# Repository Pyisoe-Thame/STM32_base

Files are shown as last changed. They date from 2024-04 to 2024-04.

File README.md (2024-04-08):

# Relay with AC PS and STM32

This is my PCB Design practice project.
Flexible programming expandable with sensors through I2C.

## Screenshots

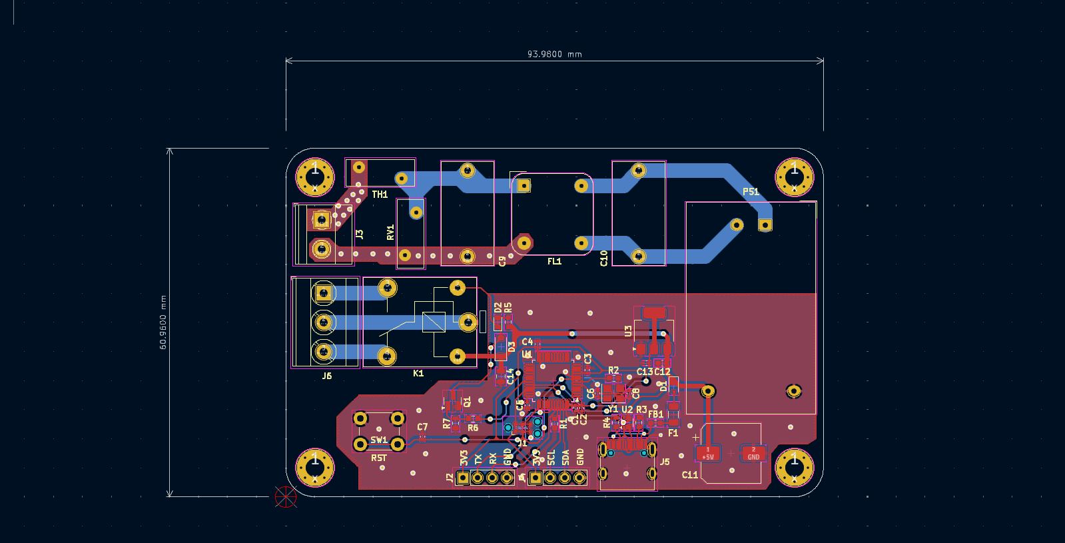
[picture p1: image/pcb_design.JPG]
PCB Design

<p align="center">PCB Design</p>

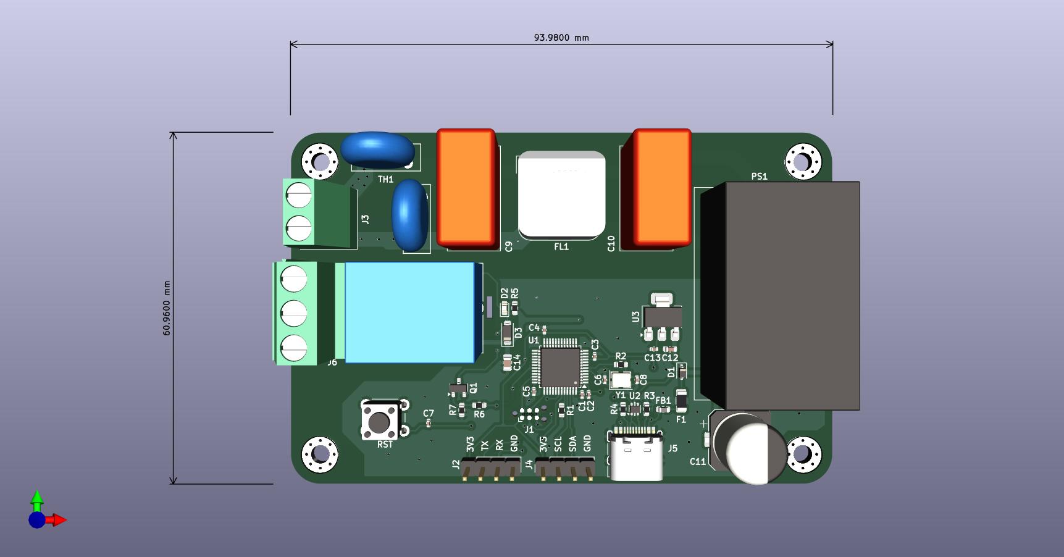
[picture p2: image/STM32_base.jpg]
3D view

<p align="center">3D View</p>

## Features

- AC Power Supply to 5V, 3V3
- STM32F103C8T6
- SWD J Tag Connector
- USB Type C 2.0
- USART, I2C
- 5V Relay

## License

[MIT](https://choosealicense.com/licenses/mit/)

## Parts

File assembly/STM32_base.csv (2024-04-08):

Reference | Value | Datasheet | Footprint | Qty | DNP
C1,C2,C3,C4,C5,C7,C13 | 100nF | ~ | Capacitor_SMD:C_0402_1005Metric | 7
C6,C8 | 22pF | ~ | Capacitor_SMD:C_0402_1005Metric | 2
C9,C10 | 1uF | ~ | Capacitor_THT:C_Rect_L18.0mm_W9.0mm_P15.00mm_FKS3_FKP3 | 2
C11 | 220uF | ~ | Capacitor_SMD:CP_Elec_10x10 | 1
C12 | 1uF | ~ | Capacitor_SMD:C_0603_1608Metric | 1
C14 | 10uF | ~ | Capacitor_SMD:C_0805_2012Metric | 1
D1 | 1N5819WS | https://datasheet.lcsc.com/lcsc/2204281430_Guangdong-Hottech-1N5819WS_C191023.pdf | Diode_SMD:D_SOD-323 | 1
D2 | LED_Small | ~ | LED_SMD:LED_0603_1608Metric | 1
D3 | 1N4148W | https://www.vishay.com/docs/85748/1n4148w.pdf | Diode_SMD:D_SOD-123 | 1
F1 | 1A | ~ | Fuse:Fuse_1206_3216Metric | 1
FB1 | FB | ~ | Inductor_SMD:L_0603_1608Metric | 1
FL1 | Choke_Schaffner_RN102-2-02-1M1 | https://www.schaffner.com/products/download/product/datasheet/rn-series-common-mode-chokes-new/ | Inductor_THT:Choke_Schaffner_RN102-04-14.0x14.0mm | 1
J2,J4 | Conn_01x04_Pin | ~ | Connector_PinHeader_2.54mm:PinHeader_1x04_P2.54mm_Vertical | 2
J3 | ST | ~ | TerminalBlock_Phoenix:TerminalBlock_Phoenix_MKDS-1,5-2-5.08_1x02_P5.08mm_Horizontal | 1
J5 | USB_C_Receptacle_USB2.0_14P | https://www.usb.org/sites/default/files/documents/usb_type-c.zip | Connector_USB:USB_C_Receptacle_HRO_TYPE-C-31-M-12 | 1
J6 | ST | ~ | TerminalBlock_Phoenix:TerminalBlock_Phoenix_MKDS-3-3-5.08_1x03_P5.08mm_Horizontal | 1
K1 | SANYOU_SRD_Form_C | http://www.sanyourelay.ca/public/products/pdf/SRD.pdf | Relay_THT:Relay_SPDT_SANYOU_SRD_Series_Form_C | 1
PS1 | HLK-PM01 | https://h.hlktech.com/download/ACDC%E7%94%B5%E6%BA%90%E6%A8%A1%E5%9D%973W%E7%B3%BB%E5%88%97/1/%E6%B5%B7%E5%87%8C%E7%A7%913W%E7%B3%BB%E5%88%97%E7%94%B5%E6%BA%9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 | Converter_ACDC:Converter_ACDC_Hi-Link_HLK-PMxx | 1
Q1 | BC817 | https://www.onsemi.com/pub/Collateral/BC818-D.pdf | Package_TO_SOT_SMD:SOT-23 | 1
R1,R2 | 47R | ~ | Resistor_SMD:R_0603_1608Metric | 2
R3,R4 | 5k1 | ~ | Resistor_SMD:R_0603_1608Metric | 2
R5 | 1k | ~ | Resistor_SMD:R_0603_1608Metric | 1
R6 | 2k2 | ~ | Resistor_SMD:R_0603_1608Metric | 1
R7 | 47k | ~ | Resistor_SMD:R_0603_1608Metric | 1
RV1 | 10D471k | ~ | Varistor:RV_Disc_D12mm_W4.7mm_P7.5mm | 1
SW1 | RST_BTN |  | Button_Switch_THT:SW_PUSH_6mm | 1
TH1 | 8ohm | ~ | Varistor:RV_Disc_D12mm_W4.7mm_P7.5mm | 1
U1 | STM32F103C8Tx | https://www.st.com/resource/en/datasheet/stm32f103c8.pdf | Package_QFP:LQFP-48_7x7mm_P0.5mm | 1
U2 | USBLC6-2P6 | https://www.st.com/resource/en/datasheet/usblc6-2.pdf | Package_TO_SOT_SMD:SOT-666 | 1
U3 | AMS1117-3.3 | http://www.advanced-monolithic.com/pdf/ds1117.pdf | Package_TO_SOT_SMD:SOT-223-3_TabPin2 | 1
Y1 | 8MHz | ~ | Crystal:Crystal_SMD_3225-4Pin_3.2x2.5mm | 1

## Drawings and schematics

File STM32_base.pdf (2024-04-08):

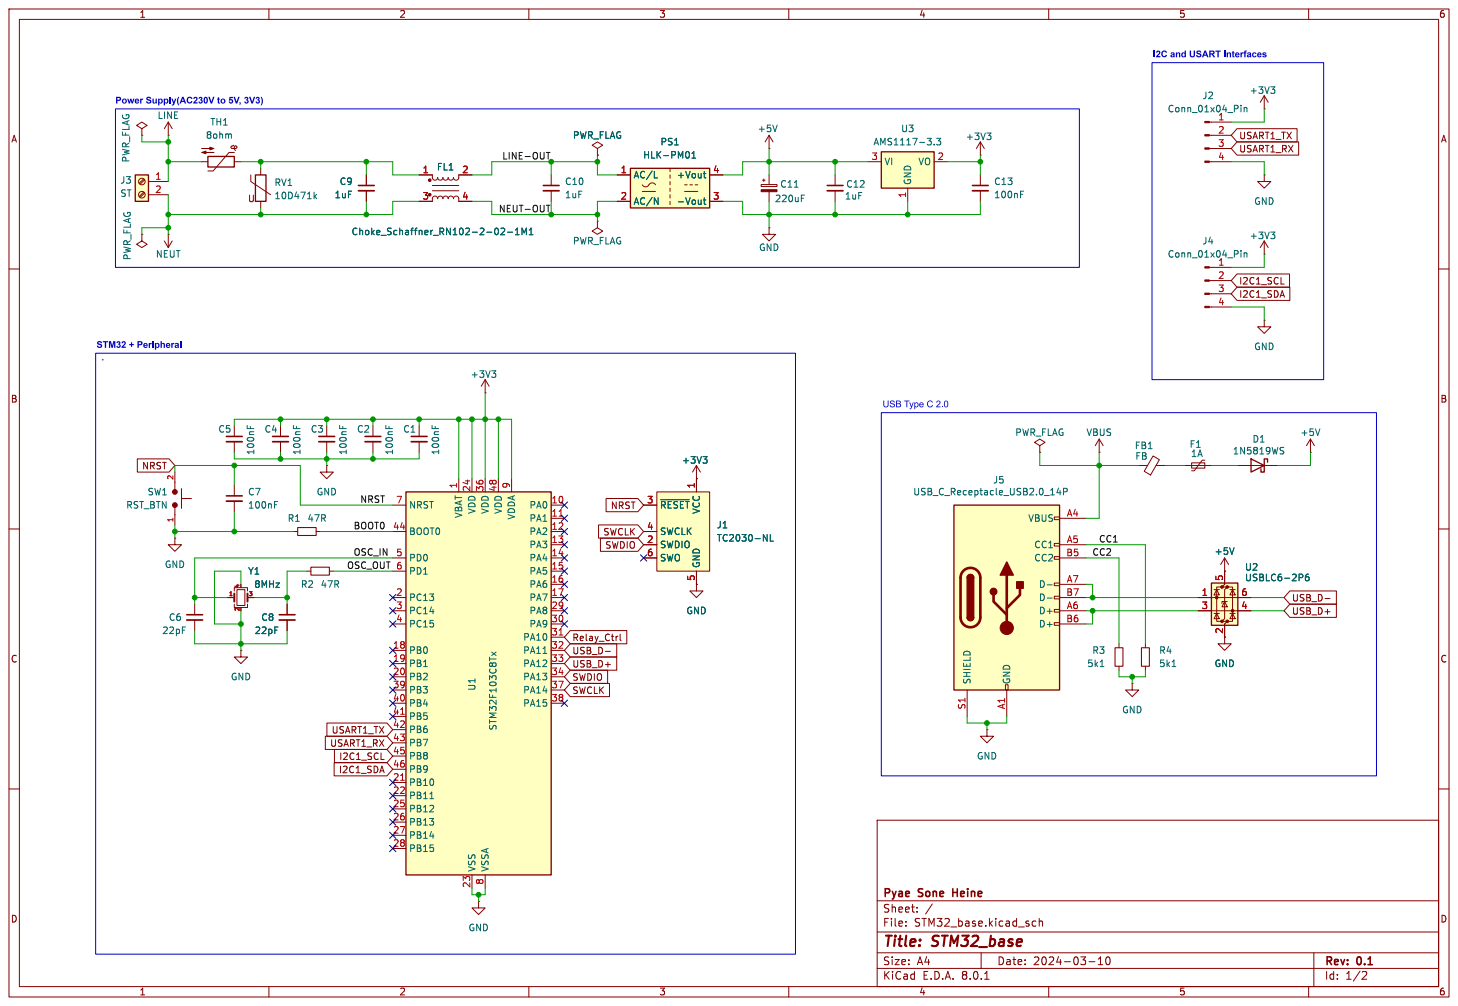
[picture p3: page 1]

1 PA0 10 PA1 11 PA2 12 PA3 13 PA4 14 PA5 15 PA6 16 PA7 17 PB0 18 PB1 19 PC13 2 PB2 20 PB10 21 PB11 22 VSS 23 VDD 24 PB12 25 PB13 26 PB14 27 PB15 28 PA8 29 PC14 3 PA9 30 PA10 31 PA11 32 PA12 33 PA13 34 VDD 36 PA14 37 PA15 38 PB3 39 PC15 4 PB4 40 PB5 41 PB6 42 PB7 43 BOOT0 44 PB8 45 PB9 46 VDD 48 PD0 5 PD1 6 NRST 7 VSSA
GND VBAT

1 SWDIO 2 ~{RESET} 3 SWCLK 4 GND

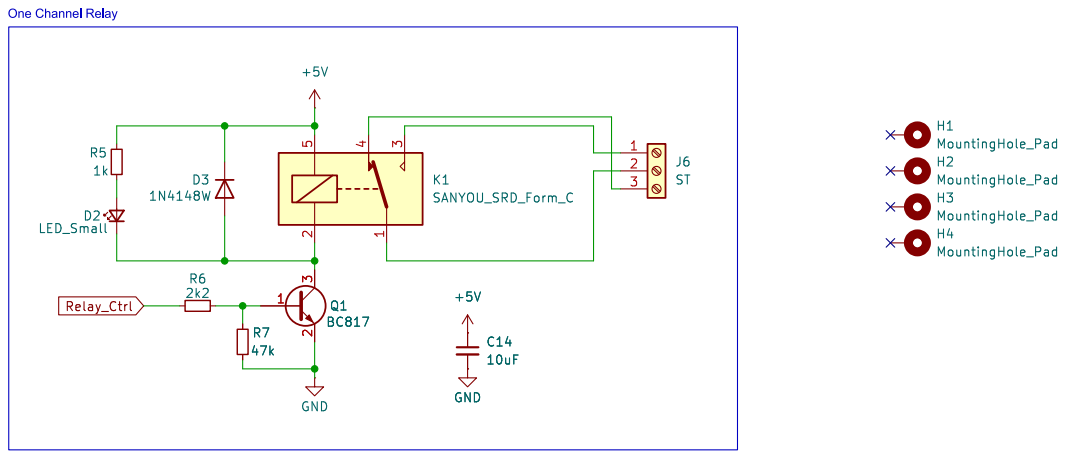
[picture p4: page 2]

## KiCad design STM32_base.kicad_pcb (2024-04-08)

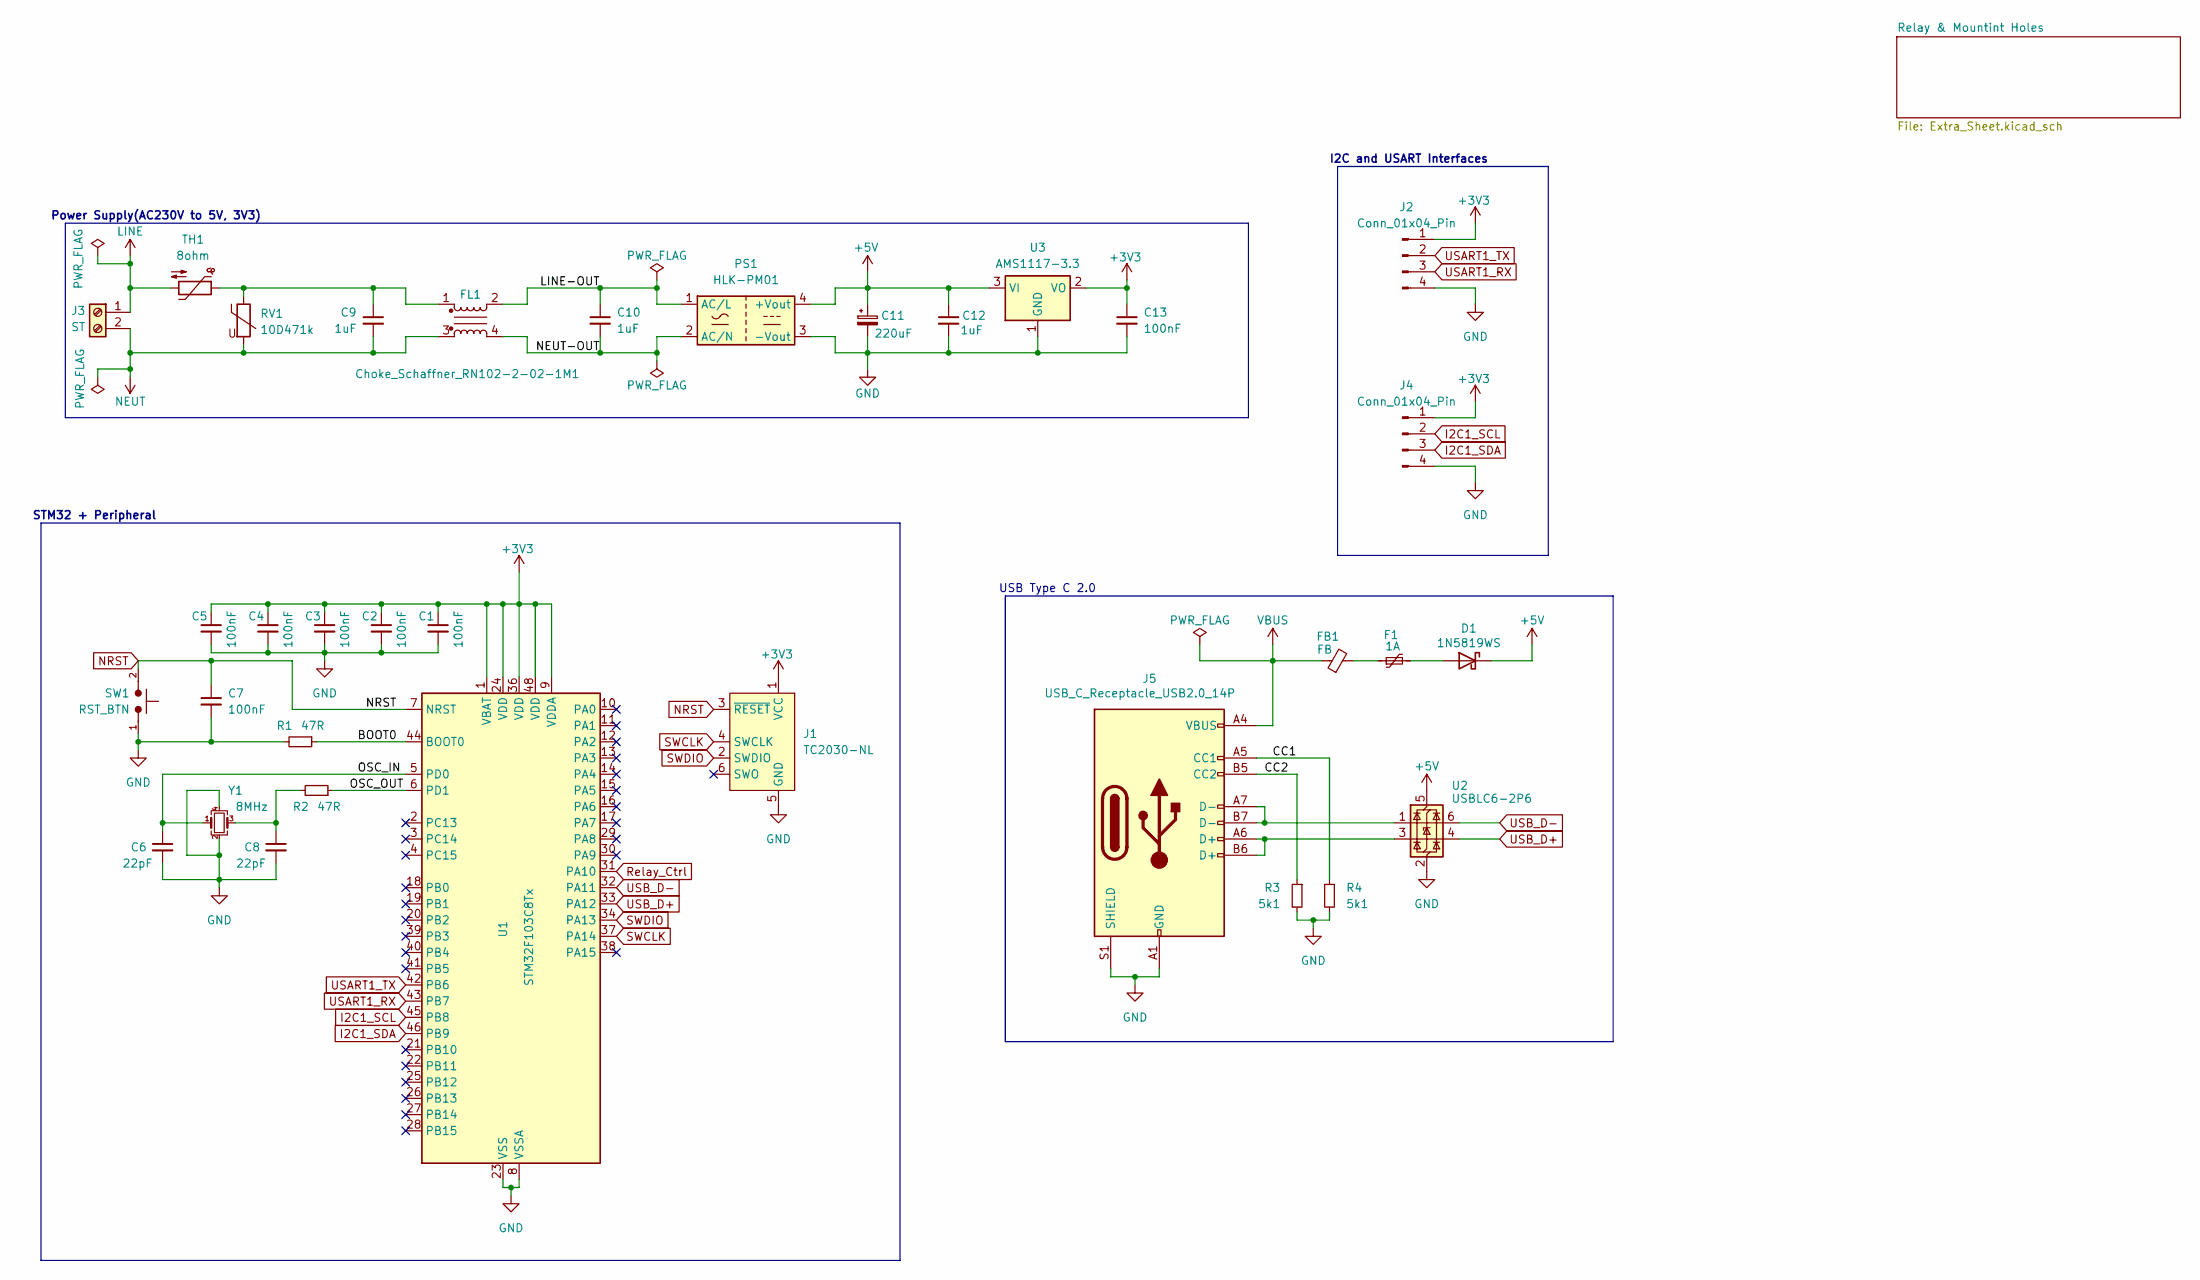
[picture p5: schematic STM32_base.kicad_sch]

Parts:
C1, C2, C3, C4, C5, C7, C13: 100nF; C_0402_1005Metric
C6, C8: 22pF; C_0402_1005Metric
C9, C10: 1uF; C_Rect_L18.0mm_W9.0mm_P15.00mm_FKS3_FKP3
C11: 220uF; CP_Elec_10x10
C12: 1uF; C_0603_1608Metric
D1: 1N5819WS; D_SOD-323
F1: 1A; Fuse_1206_3216Metric
FB1: FB; L_0603_1608Metric
FL1: Choke_Schaffner_RN102-2-02-1M1; Choke_Schaffner_RN102-04-14.0x14.0mm
J1: TC2030-NL; Tag-Connect_TC2030-IDC-NL_2x03_P1.27mm_Vertical
J2, J4: Conn_01x04_Pin; PinHeader_1x04_P2.54mm_Vertical
J3: ST; TerminalBlock_Phoenix_MKDS-1,5-2-5.08_1x02_P5.08mm_Horizont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
J5: USB_C_Receptacle_USB2.0_14P; USB_C_Receptacle_HRO_TYPE-C-31-M-12
PS1: HLK-PM01; Converter_ACDC_Hi-Link_HLK-PMxx
R1, R2: 47R; R_0603_1608Metric
R3, R4: 5k1; R_0603_1608Metric
RV1: 10D471k; RV_Disc_D12mm_W4.7mm_P7.5mm
SW1: RST_BTN; SW_PUSH_6mm
TH1: 8ohm; RV_Disc_D12mm_W4.7mm_P7.5mm
U1: STM32F103C8Tx; LQFP-48_7x7mm_P0.5mm
U2: USBLC6-2P6; SOT-666
U3: AMS1117-3.3; SOT-223-3_TabPin2
Y1: 8MHz; Crystal_SMD_3225-4Pin_3.2x2.5mm

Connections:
+3V3: C1.1, C2.1, C3.1, C4.1, C5.1, C13.1, J1.1 (VCC), J2.1, J4.1, U1.1 (VBAT), U1.9 (VDDA), U1.24 (VDD), U1.36 (VDD), U1.48 (VDD), U3.2 (VO)
+5V: C11.1, C12.1, D1.1 (K), PS1.4 (+Vout), U2.5 (VBUS), U3.3 (VI); also elsewhere on the board
/BOOT0: R1.1, U1.44 (BOOT0)
/CC1: J5.A5 (CC1), R4.1
/CC2: J5.B5 (CC2), R3.1
/LINE-OUT: C10.1, FL1.2, PS1.1 (AC/L)
/NEUT-OUT: C10.2, FL1.4, PS1.2 (AC/N)
/OSC_IN: C6.1, U1.5 (PD0), Y1.1
/OSC_OUT: R2.1, U1.6 (PD1)
GND: C1.2, C2.2, C3.2, C4.2, C5.2, C6.2, C7.2, C8.2, C11.2, C12.2, C13.2, J1.5 (GND), J2.4, J4.4, J5.A1 (GND), J5.A12 (GND), J5.B1 (GND), J5.B12 (GND), J5.S1 (SHIELD), PS1.3 (-Vout), R1.2, R3.2, R4.2, SW1.1, U1.8 (VSSA), U1.23 (VSS), U1.35 (VSS), U1.47 (VSS), U2.2 (GND), U3.1 (GND), Y1.2, Y1.4; also elsewhere on the board
I2C1_SCL: J4.2, U1.45 (PB8)
I2C1_SDA: J4.3, U1.46 (PB9)
LINE: J3.1, TH1.2
NEUT: C9.2, FL1.3, J3.2, RV1.2
NRST: C7.1, J1.3 (~RESET), SW1.2, U1.7 (NRST)
unnamed: C8.1, R2.2, Y1.3
unnamed: C9.1, FL1.1, RV1.1, TH1.1
unnamed: D1.2 (A), F1.2
unnamed: F1.1, FB1.2
unnamed: J5.A6 (D+), J5.B6 (D+), U2.3 (I/O2)
unnamed: J5.A7 (D-), J5.B7 (D-), U2.1 (I/O1)
Relay_Ctrl: U1.31 (PA10); also elsewhere on the board
SWCLK: J1.4 (SWCLK), U1.37 (PA14)
SWDIO: J1.2 (SWDIO), U1.34 (PA13)
USART1_RX: J2.3, U1.43 (PB7)
USART1_TX: J2.2, U1.42 (PB6)
USB_D+: U1.33 (PA12), U2.4 (I/O2)
USB_D-: U1.32 (PA11), U2.6 (I/O1)
VBUS: FB1.1, J5.A4 (VBUS), J5.A9 (VBUS), J5.B4 (VBUS), J5.B9 (VBUS)

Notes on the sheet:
I2C and USART Interfaces
STM32 + Peripheral
Power Supply(AC230V to 5V, 3V3)
USB Type C 2.0

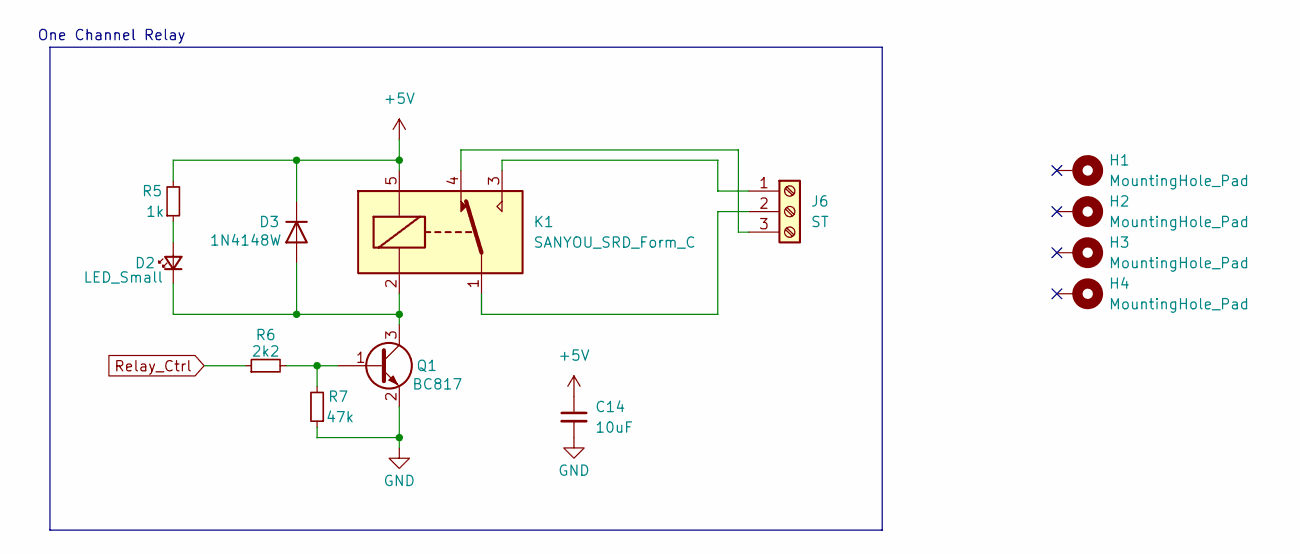
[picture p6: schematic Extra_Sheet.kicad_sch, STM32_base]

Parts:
C14: 10uF; C_0805_2012Metric
D2: LED_Small; LED_0603_1608Metric
D3: 1N4148W; D_SOD-123
H1, H2, H3, H4: MountingHole_Pad; MountingHole_3.2mm_M3_Pad_Via
J6: ST; TerminalBlock_Phoenix_MKDS-3-3-5.08_1x03_P5.08mm_Horizontal
K1: SANYOU_SRD_Form_C; Relay_SPDT_SANYOU_SRD_Series_Form_C
Q1: BC817; SOT-23
R5: 1k; R_0603_1608Metric
R6: 2k2; R_0603_1608Metric
R7: 47k; R_0603_1608Metric

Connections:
+5V: C14.1, D3.1 (K), K1.5, R5.2; also elsewhere on the board
GND: C14.2, Q1.2 (E), R7.1; also elsewhere on the board
unnamed: D2.2 (A), R5.1
unnamed: D2.1 (K), D3.2 (A), K1.2, Q1.3 (C)
unnamed: J6.1, K1.3
unnamed: J6.2, K1.1
unnamed: J6.3, K1.4
unnamed: Q1.1 (B), R6.2, R7.2
Relay_Ctrl: R6.1; also elsewhere on the board

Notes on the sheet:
One Channel Relay

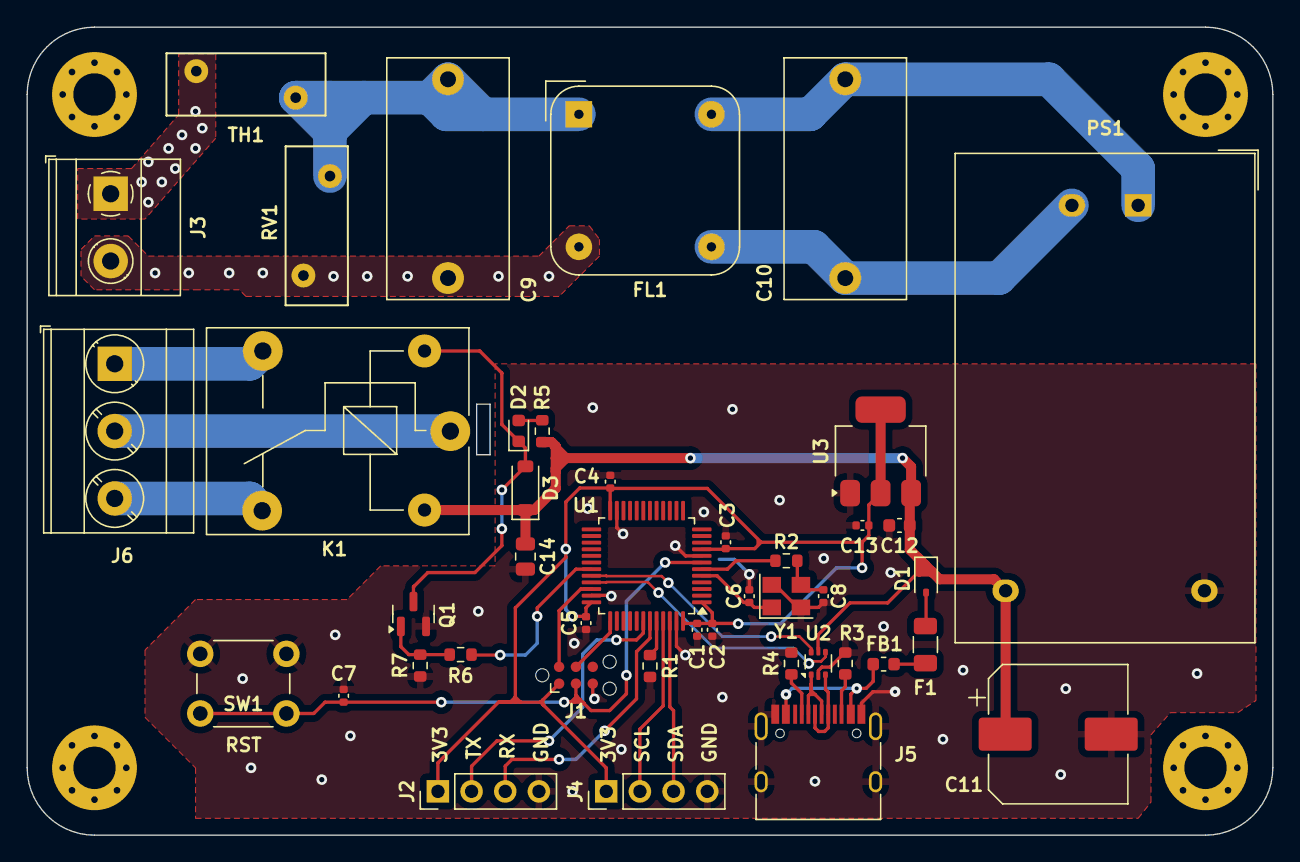
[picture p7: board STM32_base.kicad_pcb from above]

Board: 2 copper layers, 94.0 x 61.0 mm, 47 parts (0 on the bottom side), 35 nets.

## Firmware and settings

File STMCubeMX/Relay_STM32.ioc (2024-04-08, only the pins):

Mcu.UserName=STM32F103C8Tx
PA10.Signal=GPIO_Output
PA11.Signal=USB_DM
PA12.Signal=USB_DP
PA13.Signal=SYS_JTMS-SWDIO
PA14.Signal=SYS_JTCK-SWCLK
PB6.Signal=USART1_TX
PB7.Signal=USART1_RX
PB8.Signal=I2C1_SCL
PB9.Signal=I2C1_SDA
PD0-OSC_IN.Signal=RCC_OSC_IN
PD1-OSC_OUT.Signal=RCC_OSC_OUT

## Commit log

2024-04-03 PCB Components placed
    [Extra_Sheet.kicad_sch, STM32_base.kicad_pcb, STM32_base.kicad_sch]
2024-04-08 pcb finished, gerber added
    [Extra_Sheet.kicad_sch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]
2024-04-08 schematic pdf added
2024-04-08 3d view and pcb design image added
    [STM32_base.kicad_pcb]
